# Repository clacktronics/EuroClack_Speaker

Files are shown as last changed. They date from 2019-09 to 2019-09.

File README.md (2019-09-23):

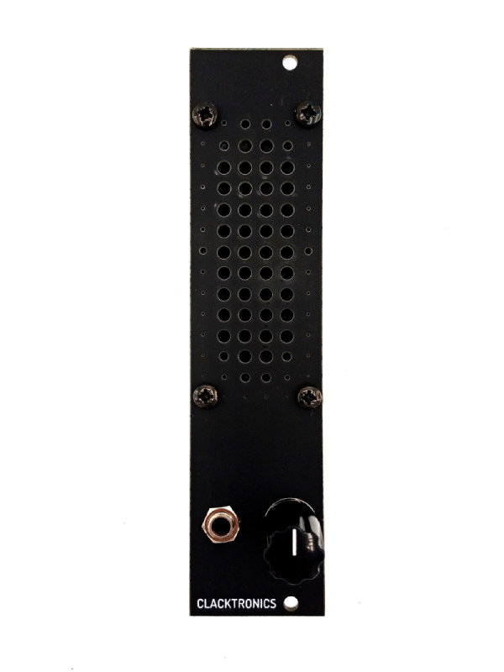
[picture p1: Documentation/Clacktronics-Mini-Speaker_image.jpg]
Image of the mini speaker module from front


# Clacktronics Mini-Speaker Kit

This project is a simple audio monitor module for your Eurorack. It consists of a speaker driver mounted onto an FR4 panel with an amplifier board. Much like the EDP Wasp or the Arp 2600, It will not be the most high definition speaker, especially lacking at the low end, but it is handy for when you may not be able to access your monitors or if you are using a small portable system.

As a kit it is designed to be simple and fast to assemble, so ideal for beginners. There are only a handful of components to solder so should give fast gratification and troubleshooting should be simple. The speaker is exactly 30.5mm wide which means it just fits into the 6HP (30mm) panel width.

* Width: 6HP
* Height: 3U
* Depth: 50mm
* Current draw idle: 5mA(+12V) 0mA(-12V) 0mA(5V)
* Current draw Active: 80mA(+12V) 0mA(-12V) 0mA(5V) (driven with 10Vpp square wave at 500kHz)

More information at [clacktronics.co.uk/euroclack](http://clacktronics.co.uk/euroclack)

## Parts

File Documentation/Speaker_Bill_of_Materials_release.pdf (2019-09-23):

Description | Package | Manufacturer | MPN | Supplier | Supplier N | Quant

Component bag
LM386N-4/NOPB | DIP8 | Texas Instruments | LM386N-4/NOPB | RS Components | 534-2911 | 1
LM386N-4/NOPB | DIP8 | Texas Instruments | LM386N-4/NOPB | Mouser | 926-LM386N-4/NOPB 1
DIL-8 socket | | Rapid Electronics | 22-0107 | Rapid Electronics | 22-0107 | 1
Anti-static Foam square | | | | | | 1
100nF 20% 25V 5mm Y5V Ceramic Disc Capacitor | 5mm pitch | Suntan | TS15001E104MSBFBOR | Rapid Electronics | 08-0235 | 3
10uF 20% 35V 105°C P: 2mm Radial Electrolytic Capacitor | 5x11mm, 2mm pitch Forever | | HT 10U 35V | Rapid Electronics | 11-1220 | 2
RB 1000U 16V 85°C Radial Lead Aluminium Electrolytic Capacitor | 10x17mm, 5mmForever | | RB 1000U 16V | Rapid Electronics | 11-0290 | 1
1000µF 20% 16V 105°C 2K hrs Radial Alum Elec Capacitor | 10 x 17mm, 5mm pitch Suntan | | TS14011C102MSB0B0R | Rapid Electronics | 11-3516 | 1

Reistor 1/4 Watt 10ohm
Reistor 1/4 Watt 470kohm
10 Way IDC Straight Boxed Header 2.54mm Pitch | TruConnect | 19-0033 | Rapid Electronics | 19-0033 | 1
Thonkiconn jack | Thonk | PJ398SM | Thonk | Thonkiconn | 1
SPECIAL! – VERTICAL – CENTRE DETENT | Alpha | | Thonk | ? | 1
Davies 1900h Clone – T18 Shaft Black | Thonk | | Thonk | Thonk | 1
Washer and Hex nut (included in pot) | | | | 1
Hex nut | | | Thonk | 1
Screws M3 pan head pozi black | RS Pro | 483-0934 | RS Components | 6
M3 Nut | | | | 4

Tissue paper wrap
ABS-235-RC 8Ω 2W Miniature Speaker | Alan Butcher Components ABS-235-RC | | | ABS-235-RC | 1
RS PRO 8Ω 2W Miniature Speaker 70 x 30.5 x 23mm (LxWxD) | RS Pro | ABS-235-RC | RS Components | 817-9132 | 1
PCB front panel 128.5x30 no HASL | | | | | 1
PCB 30x48 HASL | | | | | 1

Packaging
IDC cable | | | | Thonk | | 1
Anti-static bag | 6x10 | LCSC | C260957 | LCSC | C260957 | 1
Black plastic bag | 102x140 | Priory Direct | | | | 1
Sticker | | pixart print | | | | 1

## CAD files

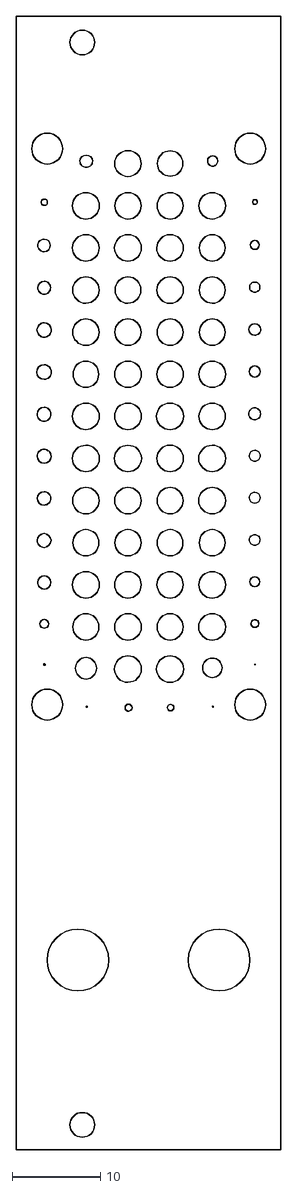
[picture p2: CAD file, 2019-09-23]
Mini-Speaker_Amplifier/design_files/panel_design.dxf
30.0 x 128.5

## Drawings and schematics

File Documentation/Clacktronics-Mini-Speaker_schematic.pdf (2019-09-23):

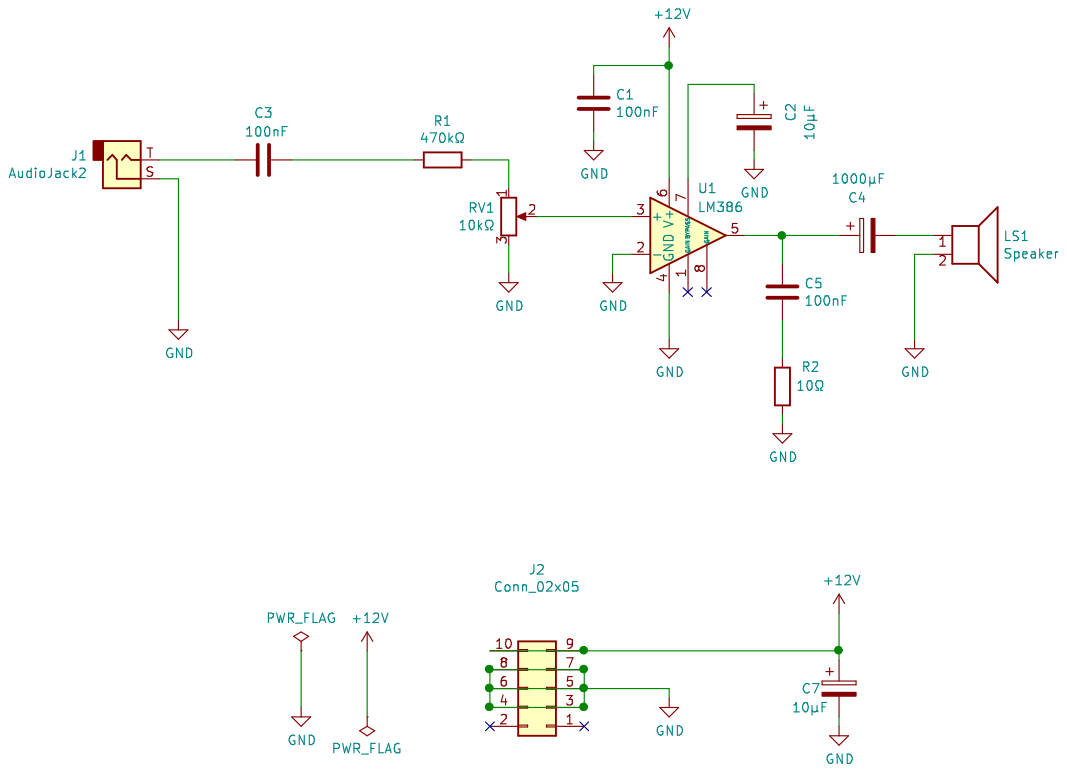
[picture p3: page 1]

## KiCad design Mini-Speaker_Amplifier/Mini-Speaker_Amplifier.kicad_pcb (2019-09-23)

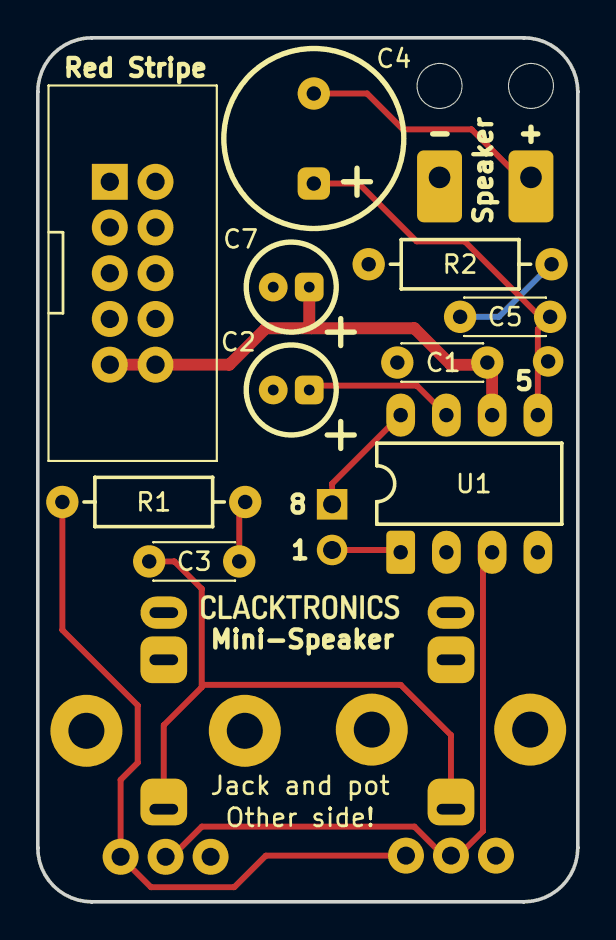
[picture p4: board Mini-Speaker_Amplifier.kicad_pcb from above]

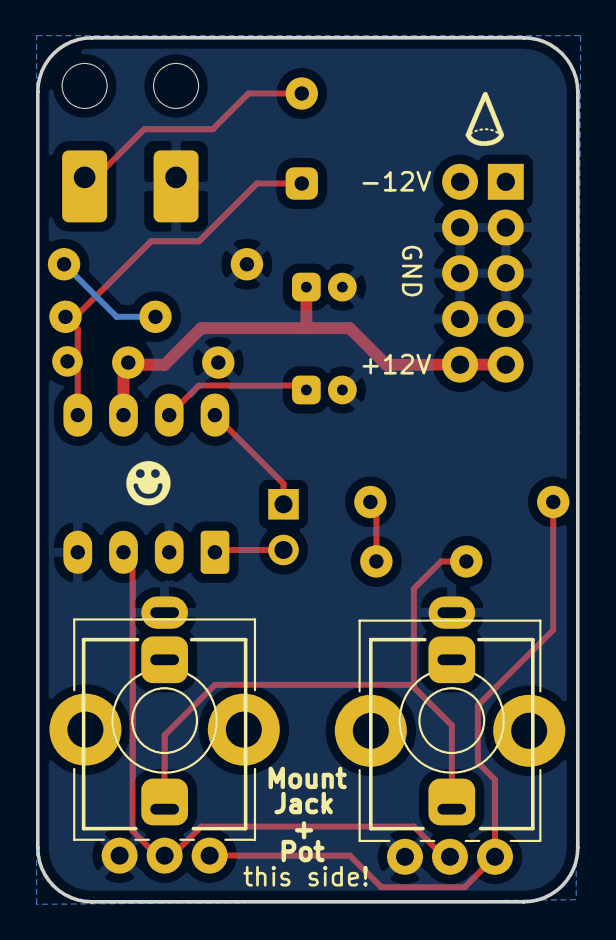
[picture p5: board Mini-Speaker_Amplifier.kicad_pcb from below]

Board: 2 copper layers, 30.0 x 48.0 mm, 16 parts (4 on the bottom side), 12 nets.

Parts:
C1, C3, C5: 100nF; C_TH_Disc_P5.00mm
C2, C7: 10μF; C_TH_Elec_5mm_P2mm
C4: 1000μF; C_TH_Elec_10mm_P5mm
J1, J1#2: AudioJack2; PJ398SM
J2: Conn_02x05; IDC-Header_2x05_P2.54mm_Vertical
J3: Conn_01x02; PinHeader_1x02_P2.54mm_Vertical
LS1: Speaker; Conn_speaker_pads
R1: 470k; R_TH_Axial_250mw_P10.16mm_Horizontal
R2: 10; R_TH_Axial_250mw_P10.16mm_Horizontal
RV1, RV1#2: 10k; POT_TH_Alps_RK09K_Single_Vertical
U1: LM386-4; DIP-8_W7.62mm

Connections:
+12V: C1.1, C7.1, J2.9, J2.10, U1.6
GND: C1.2, C2.2, C7.2, J1.S, J1#2.S, J2.3, J2.4, J2.5, J2.6, J2.7, J2.8, LS1.2, R2.1, RV1.3, RV1#2.3, U1.2, U1.4
unnamed: C2.1, U1.7
unnamed: C3.1, R1.2
unnamed: C3.2, J1.T, J1#2.T
unnamed: C4.1, C5.1, U1.5
unnamed: C4.2, LS1.1
unnamed: C5.2, R2.2
unnamed: J3.1, U1.8
unnamed: J3.2, U1.1
unnamed: R1.1, RV1.1, RV1#2.1
unnamed: RV1.2, RV1#2.2, U1.3
